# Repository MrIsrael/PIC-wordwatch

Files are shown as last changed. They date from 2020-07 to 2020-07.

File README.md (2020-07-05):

# WordWatch with PIC 16F886 (spanish)
- **This project contains all designs, files and code to build a DIY LED watch, wall mountable, which displays the time with letters, in spanish.**<br />
Resolution: 5 minutes. The words change each 5 minutes.<br />
You can find an example of how it looks when finished, opening image "Wordwatch finished.jpg".<br />
Entire design was built around PIC 16F886 from Microchip.<br />
Schematic and PCB design made using Autodesk EAGLE 8.0.1.<br />
Assembler code edited and compiled using Microchip MPLAB IDE v8.92.<br />
PICkit 2 was used for .hex transfer to microcontroller.<br />

## Instructions
--> Check the components listed in .sch file.<br />
--> Build the PCB using the PDF prints. There is a great guide to do it yourself, [here] (https://www.youtube.com/watch?v=lvNCKwAcg90).<br />
--> Burn the .hex to PIC 16F886, using a PICkit 2 or compatible PIC programmer.<br />
--> Use the "front layout" images to print a scale screen for the leds. I suggest create a wood screen, etching the letters with laser cutter.<br />
--> Use any AC/DC adaptor to power the clock. Minimum output voltage - current required: 6V DC, 300 mA.<br />

## How to set time
--> Once powered on, press the button to enter set mode. Words will start to blink.<br />
--> Press button again to change and set hours.<br />
--> Wait 10 seconds without pressing the button. Now minutes start to blink.<br />
--> Press button to change and set minutes.<br />
--> Wait another 10 seconds without pressing the button. Program will return to normal mode.<br />

## Maintainer
- [Israel Uribe](https://github.com/MrIsrael)

## License
MIT © [WordWatch](https://github.com/MrIsrael/PIC-wordwatch)

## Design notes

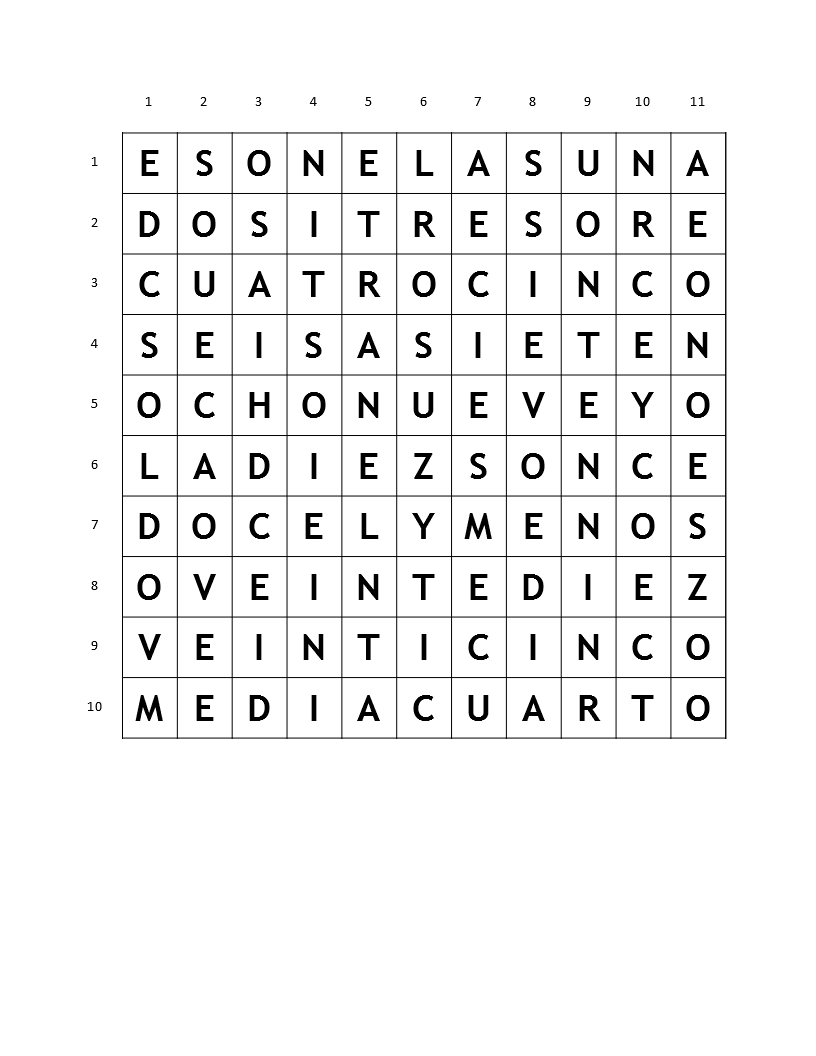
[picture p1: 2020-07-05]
Front layout (black & white).png

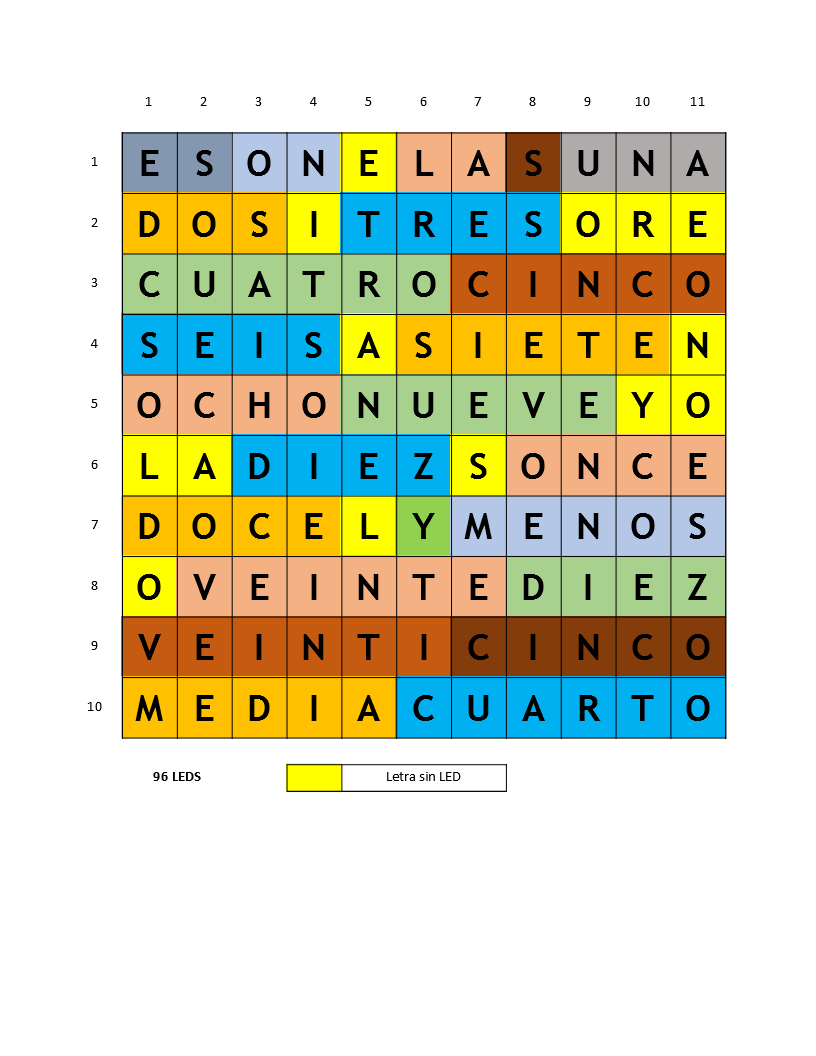
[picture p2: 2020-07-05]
Front layout (color).png

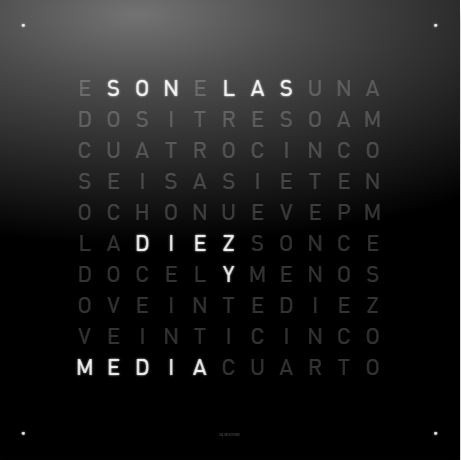
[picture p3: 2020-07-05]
Wordwatch finished.jpg

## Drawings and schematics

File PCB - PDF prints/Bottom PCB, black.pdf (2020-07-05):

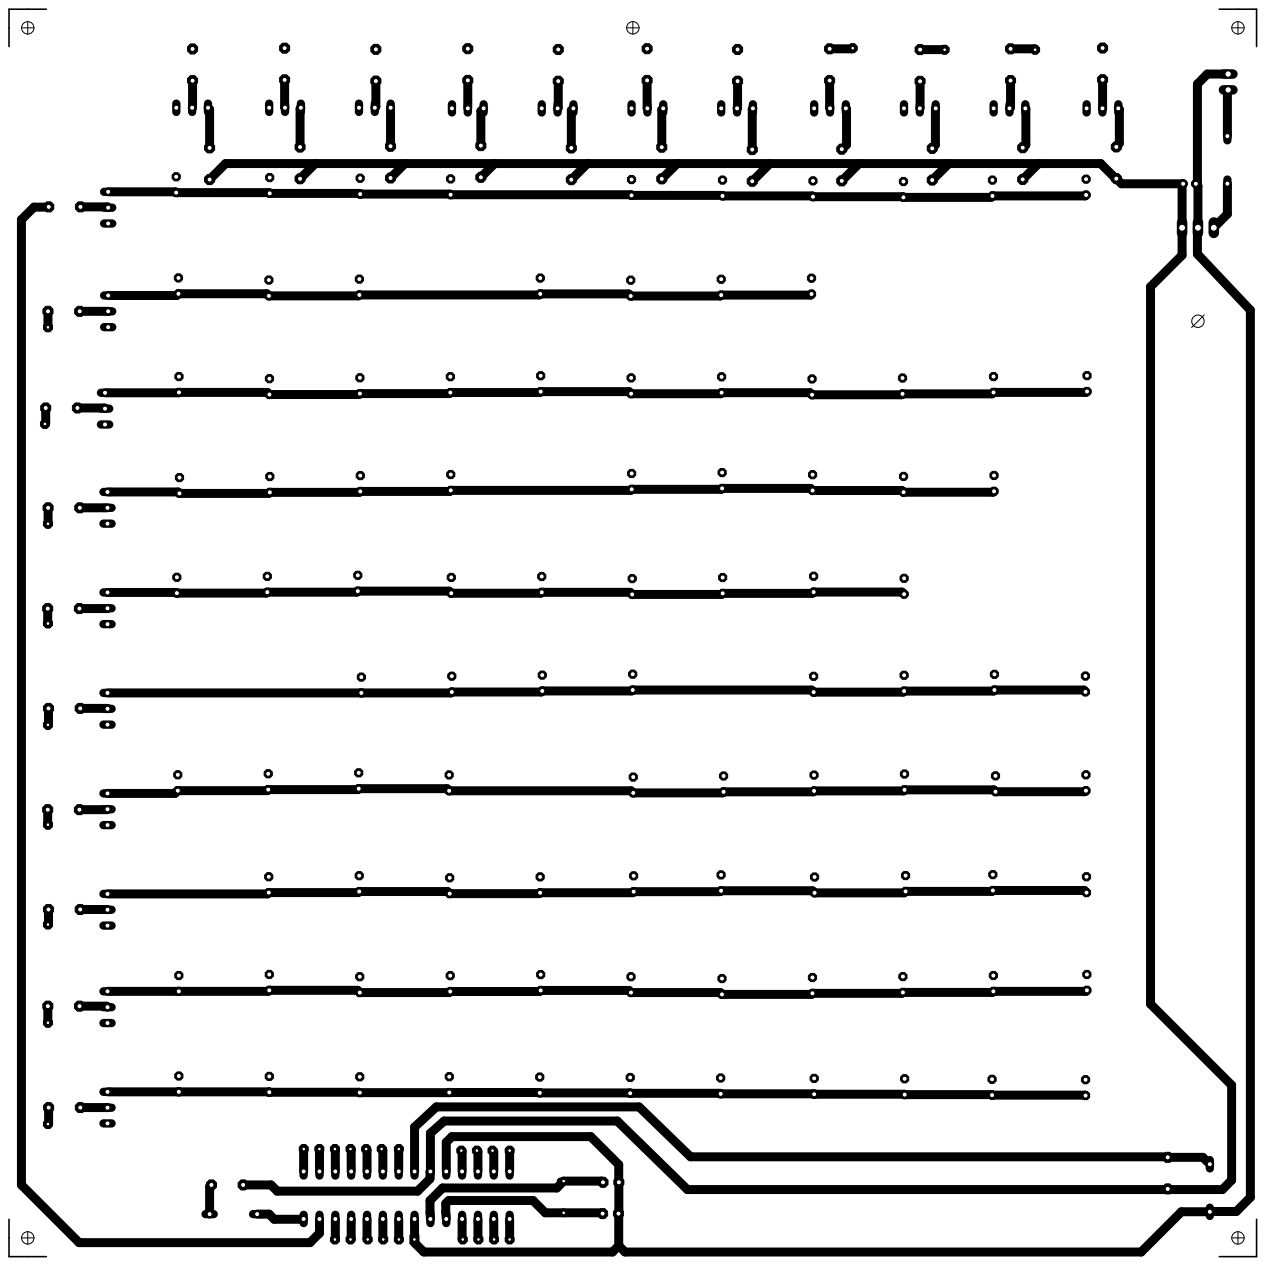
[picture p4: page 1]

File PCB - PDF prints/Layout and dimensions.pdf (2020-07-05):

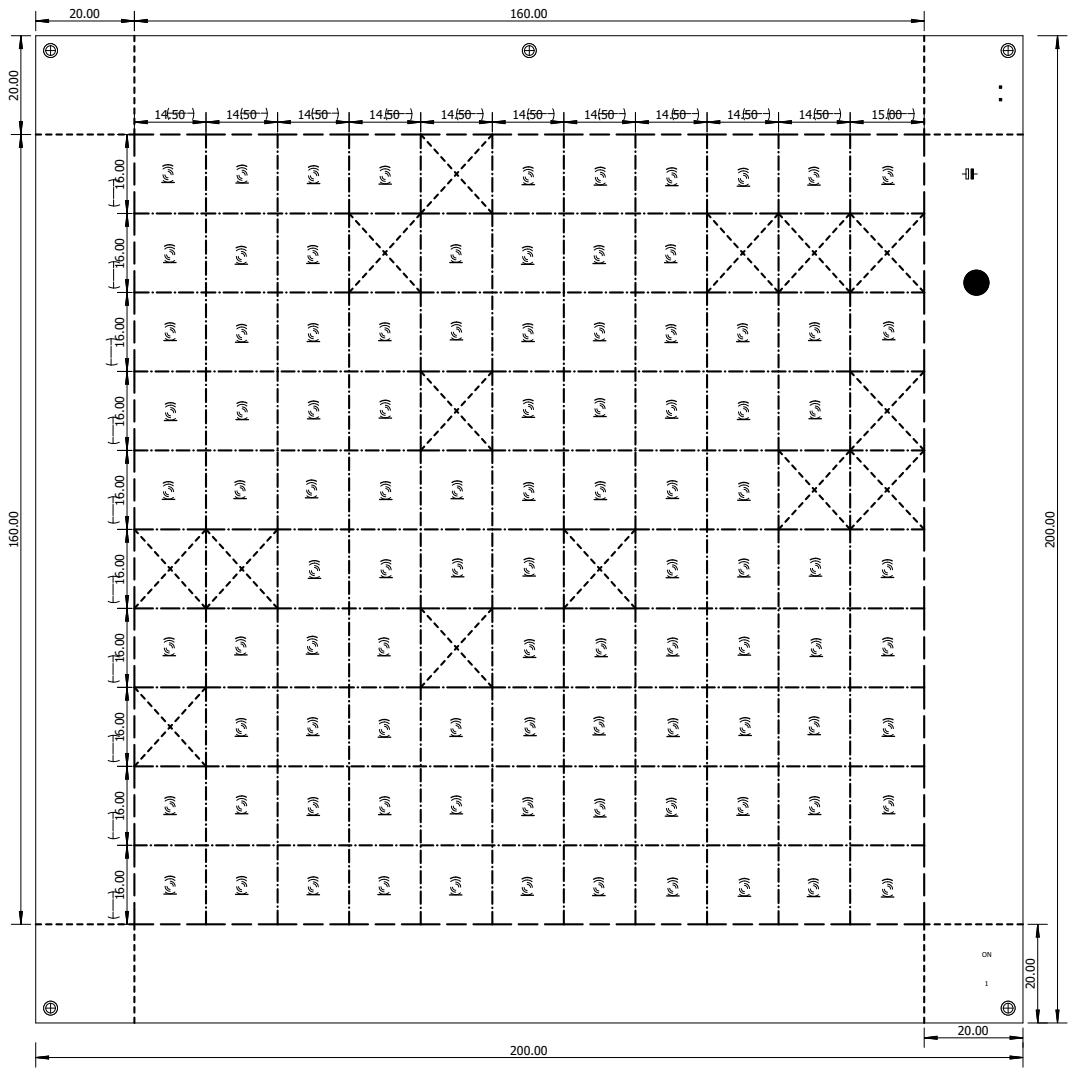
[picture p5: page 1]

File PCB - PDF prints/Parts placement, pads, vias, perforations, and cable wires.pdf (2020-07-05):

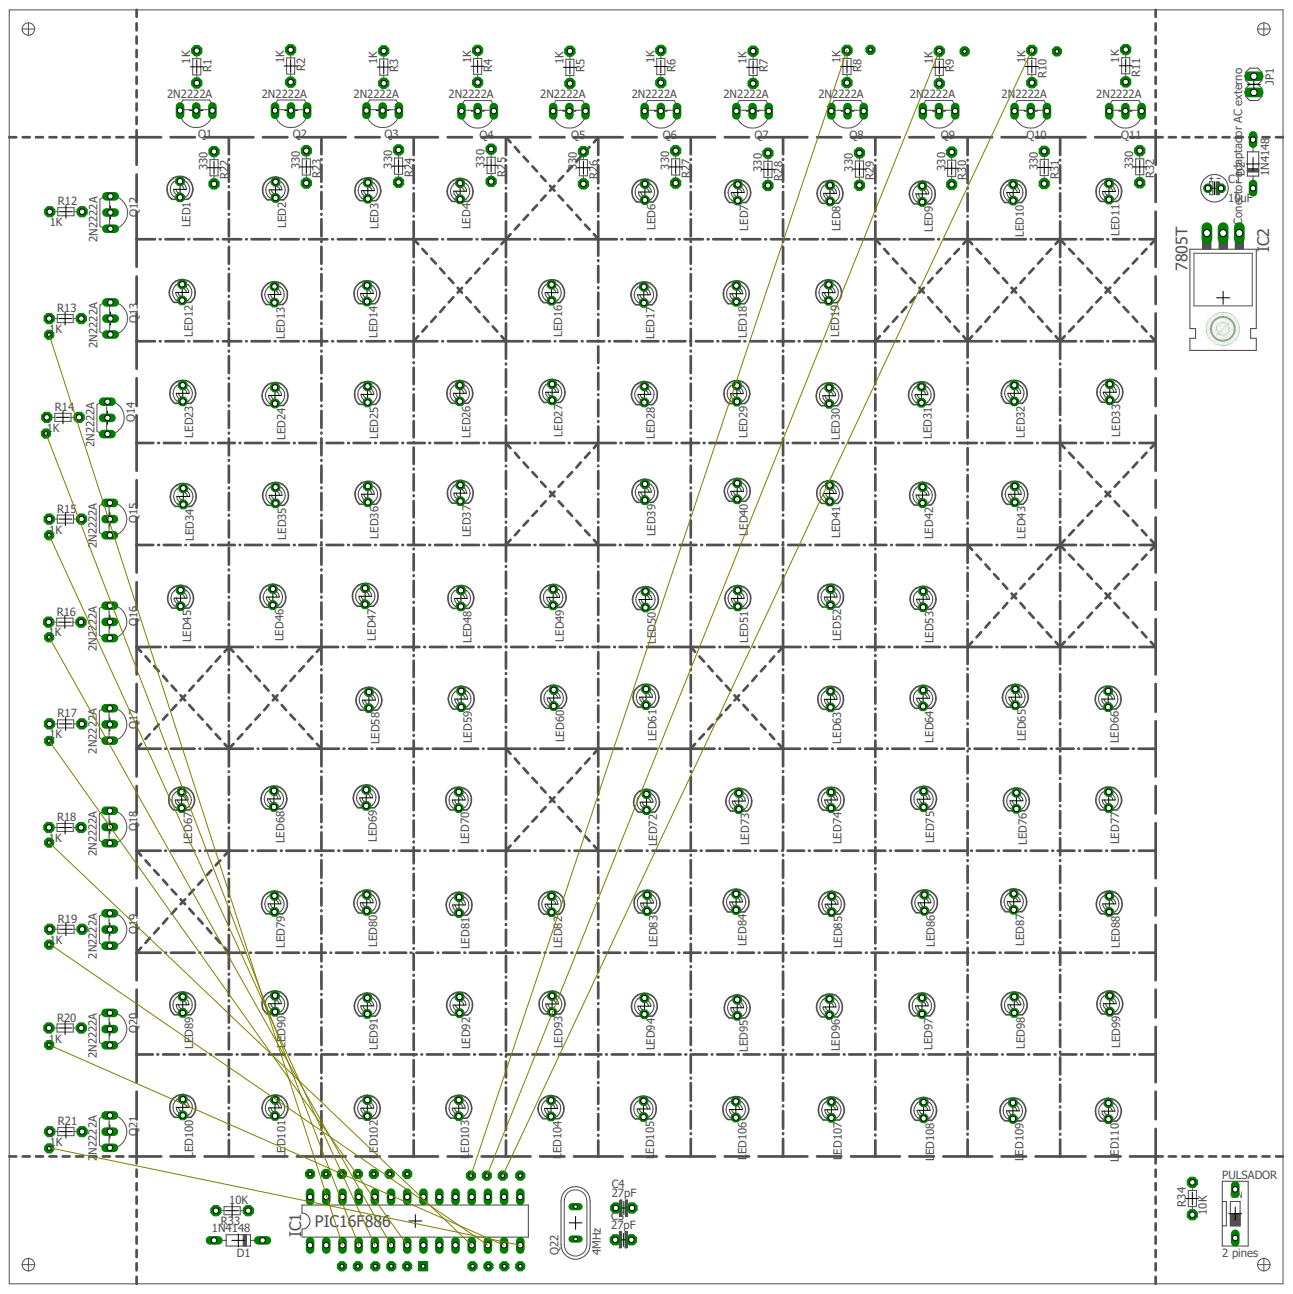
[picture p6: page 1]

Conector adaptador AC externo

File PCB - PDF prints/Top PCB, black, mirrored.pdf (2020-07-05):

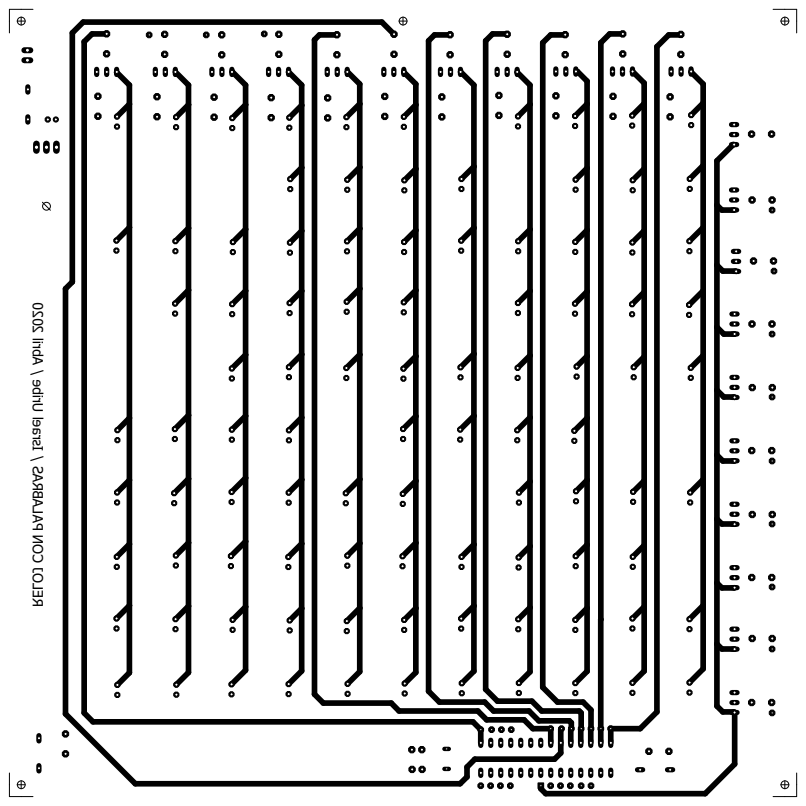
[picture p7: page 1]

RELOJ CON PALABRAS / Israel Uribe / Abril 2020

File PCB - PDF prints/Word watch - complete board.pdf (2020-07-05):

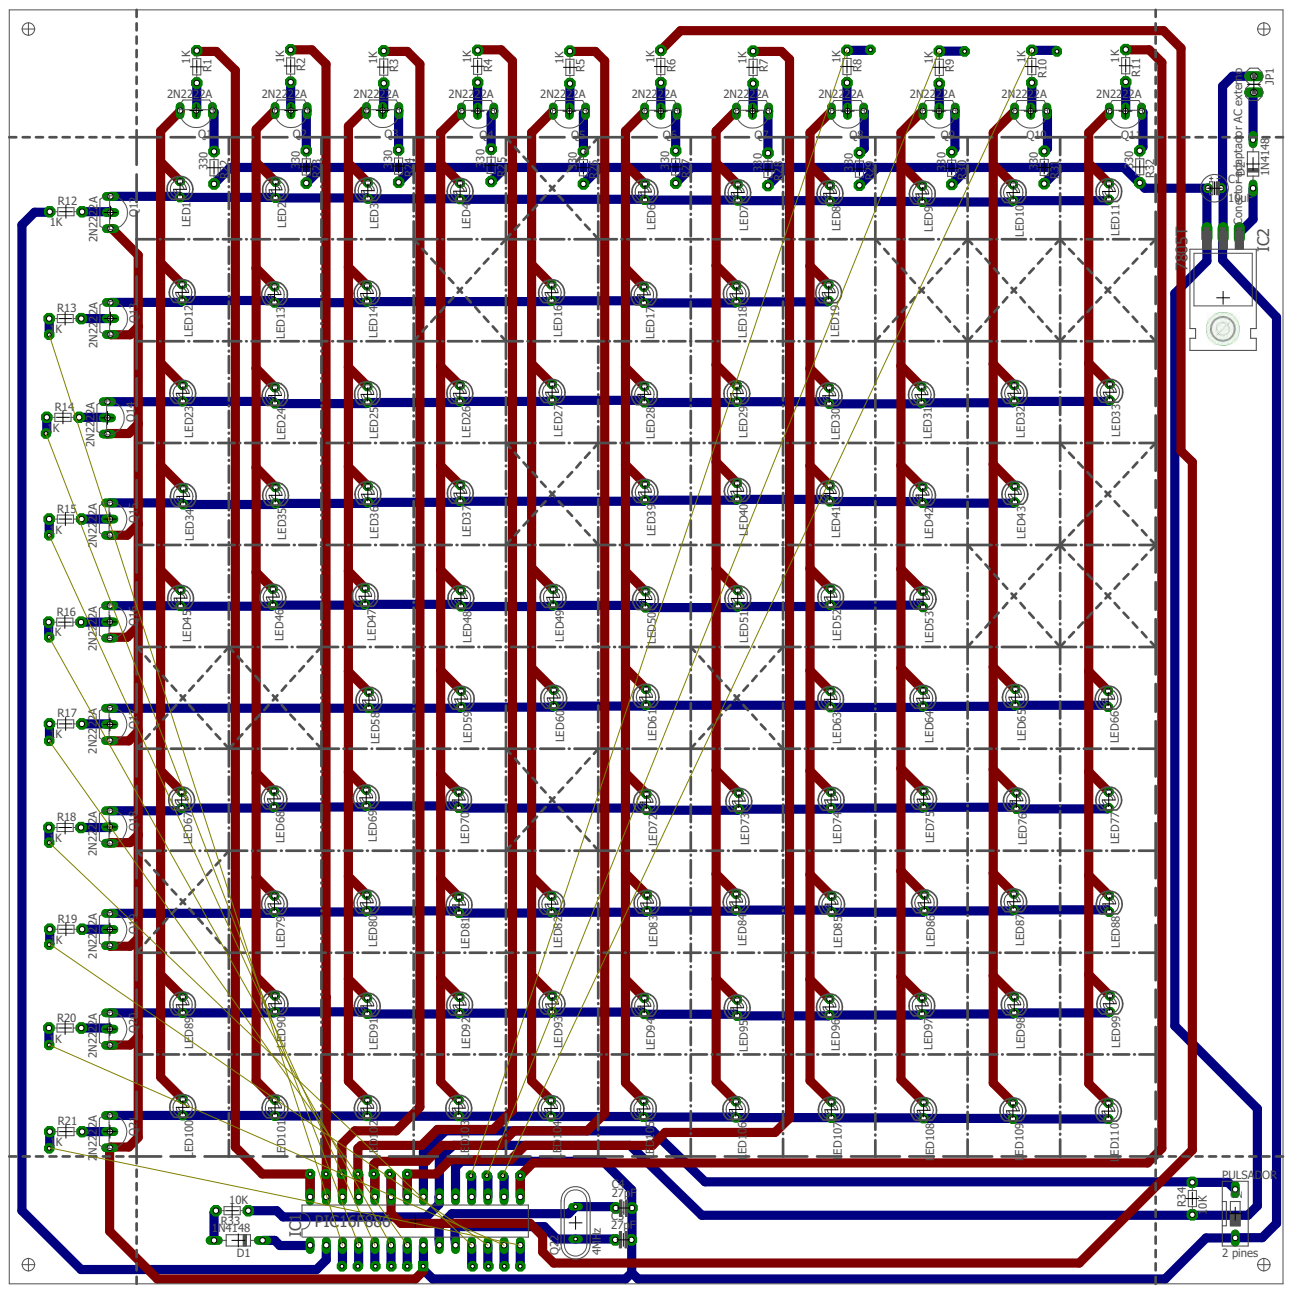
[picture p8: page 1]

Conector adaptador AC externo

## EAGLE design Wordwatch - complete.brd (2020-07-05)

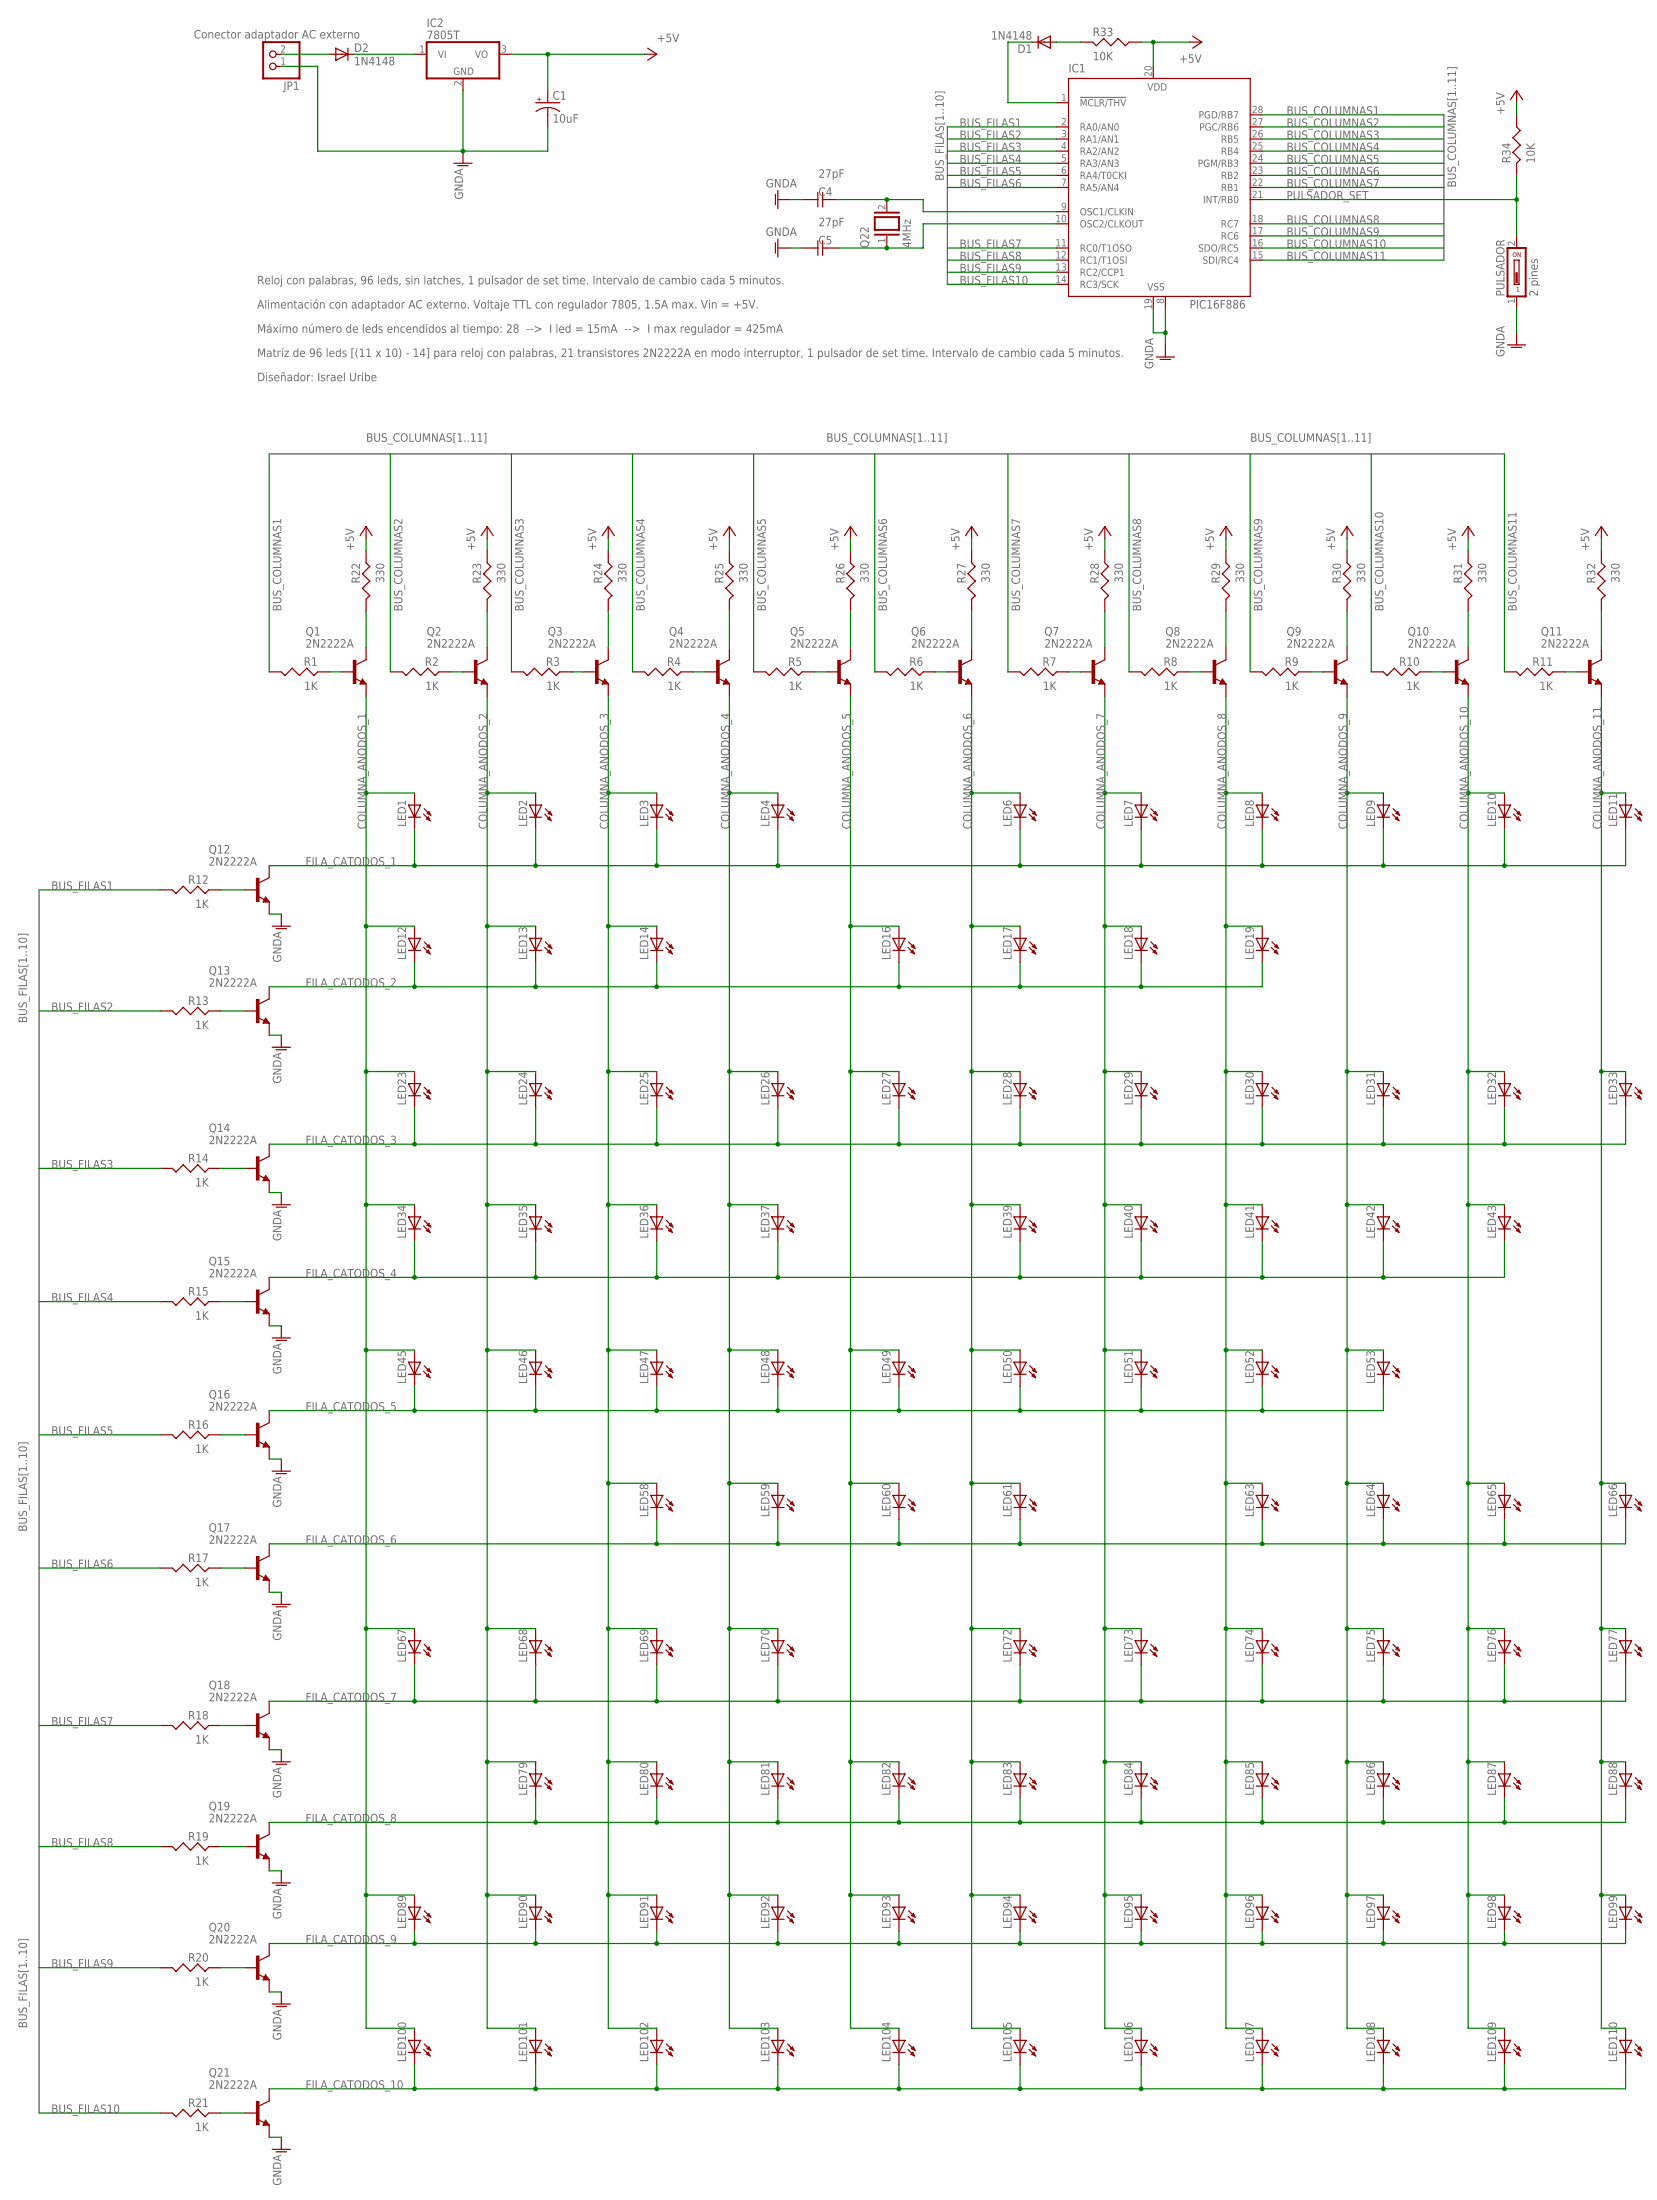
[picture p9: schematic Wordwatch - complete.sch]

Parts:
C1: 10uF; E2-4
C4, C5: 27pF; C-2,5
D1, D2: 1N4148; D-7.5
IC1: PIC16F886; DIL28-3
IC2: 7805T; TO220H
JP1: Conector adaptador AC externo; 1X02
LED1, LED2, LED3, LED4, LED6, LED7, LED8, LED9, LED10, LED11, LED12, LED13, LED14, LED16, LED17, LED18, LED19, LED23, LED24, LED25, LED26, LED27, LED28, LED29, LED30, LED31, LED32, LED33, LED34, LED35, LED36, LED37, LED39, LED40, LED41, LED42, LED43, LED45, LED46, LED47, LED48, LED49, LED50, LED51, LED52, LED53, LED58, LED59, LED60, LED61, LED63, LED64, LED65, LED66, LED67, LED68, LED69, LED70, LED72, LED73, LED74, LED75, LED76, LED77, LED79, LED80, LED81, LED82, LED83, LED84, LED85, LED86, LED87, LED88, LED89, LED90, LED91, LED92, LED93, LED94, LED95, LED96, LED97, LED98, LED99, LED100, LED101, LED102, LED103, LED104, LED105, LED106, LED107, LED108, LED109, LED110: LED3MM
PULSADOR: 2 pines; DS-01
Q1, Q2, Q3, Q4, Q5, Q6, Q7, Q8, Q9, Q10, Q11, Q12, Q13, Q14, Q15, Q16, Q17, Q18, Q19, Q20, Q21: 2N2222A; TO92-CBE
Q22: 4MHz; QS
R1, R2, R3, R4, R5, R6, R7, R8, R9, R10, R11, R12, R13, R14, R15, R16, R17, R18, R19, R20, R21: 1K; R-5
R22, R23, R24, R25, R26, R27, R28, R29, R30, R31, R32: 330; R-5
R33, R34: 10K; R-5

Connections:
+5V: C1.+, IC1.20 (VDD), IC2.3 (VO), R22.2, R23.2, R24.2, R25.2, R26.2, R27.2, R28.2, R29.2, R30.2, R31.2, R32.2, R33.1, R34.1
BUS_COLUMNAS1: IC1.28 (PGD/RB7), R1.1
BUS_COLUMNAS2: IC1.27 (PGC/RB6), R2.1
BUS_COLUMNAS3: IC1.26 (RB5), R3.1
BUS_COLUMNAS4: IC1.25 (RB4), R4.1
BUS_COLUMNAS5: IC1.24 (PGM/RB3), R5.1
BUS_COLUMNAS6: IC1.23 (RB2), R6.1
BUS_COLUMNAS7: IC1.22 (RB1), R7.1
BUS_COLUMNAS8: IC1.18 (RC7), R8.1
BUS_COLUMNAS9: IC1.17 (RC6), R9.1
BUS_COLUMNAS10: IC1.16 (SDO/RC5), R10.1
BUS_COLUMNAS11: IC1.15 (SDI/RC4), R11.1
BUS_FILAS1: IC1.2 (RA0/AN0), R12.1
BUS_FILAS2: IC1.3 (RA1/AN1), R13.1
BUS_FILAS3: IC1.4 (RA2/AN2), R14.1
BUS_FILAS4: IC1.5 (RA3/AN3), R15.1
BUS_FILAS5: IC1.6 (RA4/T0CKI), R16.1
BUS_FILAS6: IC1.7 (RA5/AN4), R17.1
BUS_FILAS7: IC1.11 (RC0/T1OSO), R18.1
BUS_FILAS8: IC1.12 (RC1/T1OSI), R19.1
BUS_FILAS9: IC1.13 (RC2/CCP1), R20.1
BUS_FILAS10: IC1.14 (RC3/SCK), R21.1
COLUMNA_ANODOS_1: LED1.A, LED12.A, LED23.A, LED34.A, LED45.A, LED67.A, LED89.A, LED100.A, Q1.E
COLUMNA_ANODOS_2: LED2.A, LED13.A, LED24.A, LED35.A, LED46.A, LED68.A, LED79.A, LED90.A, LED101.A, Q2.E
COLUMNA_ANODOS_3: LED3.A, LED14.A, LED25.A, LED36.A, LED47.A, LED58.A, LED69.A, LED80.A, LED91.A, LED102.A, Q3.E
COLUMNA_ANODOS_4: LED4.A, LED26.A, LED37.A, LED48.A, LED59.A, LED70.A, LED81.A, LED92.A, LED103.A, Q4.E
COLUMNA_ANODOS_5: LED16.A, LED27.A, LED49.A, LED60.A, LED82.A, LED93.A, LED104.A, Q5.E
COLUMNA_ANODOS_6: LED6.A, LED17.A, LED28.A, LED39.A, LED50.A, LED61.A, LED72.A, LED83.A, LED94.A, LED105.A, Q6.E
COLUMNA_ANODOS_7: LED7.A, LED18.A, LED29.A, LED40.A, LED51.A, LED73.A, LED84.A, LED95.A, LED106.A, Q7.E
COLUMNA_ANODOS_8: LED8.A, LED19.A, LED30.A, LED41.A, LED52.A, LED63.A, LED74.A, LED85.A, LED96.A, LED107.A, Q8.E
COLUMNA_ANODOS_9: LED9.A, LED31.A, LED42.A, LED53.A, LED64.A, LED75.A, LED86.A, LED97.A, LED108.A, Q9.E
COLUMNA_ANODOS_10: LED10.A, LED32.A, LED43.A, LED65.A, LED76.A, LED87.A, LED98.A, LED109.A, Q10.E
COLUMNA_ANODOS_11: LED11.A, LED33.A, LED66.A, LED77.A, LED88.A, LED99.A, LED110.A, Q11.E
FILA_CATODOS_1: LED1.K (C), LED2.K (C), LED3.K (C), LED4.K (C), LED6.K (C), LED7.K (C), LED8.K (C), LED9.K (C), LED10.K (C), LED11.K (C), Q12.C
FILA_CATODOS_2: LED12.K (C), LED13.K (C), LED14.K (C), LED16.K (C), LED17.K (C), LED18.K (C), LED19.K (C), Q13.C
FILA_CATODOS_3: LED23.K (C), LED24.K (C), LED25.K (C), LED26.K (C), LED27.K (C), LED28.K (C), LED29.K (C), LED30.K (C), LED31.K (C), LED32.K (C), LED33.K (C), Q14.C
FILA_CATODOS_4: LED34.K (C), LED35.K (C), LED36.K (C), LED37.K (C), LED39.K (C), LED40.K (C), LED41.K (C), LED42.K (C), LED43.K (C), Q15.C
FILA_CATODOS_5: LED45.K (C), LED46.K (C), LED47.K (C), LED48.K (C), LED49.K (C), LED50.K (C), LED51.K (C), LED52.K (C), LED53.K (C), Q16.C
FILA_CATODOS_6: LED58.K (C), LED59.K (C), LED60.K (C), LED61.K (C), LED63.K (C), LED64.K (C), LED65.K (C), LED66.K (C), Q17.C
FILA_CATODOS_7: LED67.K (C), LED68.K (C), LED69.K (C), LED70.K (C), LED72.K (C), LED73.K (C), LED74.K (C), LED75.K (C), LED76.K (C), LED77.K (C), Q18.C
FILA_CATODOS_8: LED79.K (C), LED80.K (C), LED81.K (C), LED82.K (C), LED83.K (C), LED84.K (C), LED85.K (C), LED86.K (C), LED87.K (C), LED88.K (C), Q19.C
FILA_CATODOS_9: LED89.K (C), LED90.K (C), LED91.K (C), LED92.K (C), LED93.K (C), LED94.K (C), LED95.K (C), LED96.K (C), LED97.K (C), LED98.K (C), LED99.K (C), Q20.C
FILA_CATODOS_10: LED100.K (C), LED101.K (C), LED102.K (C), LED103.K (C), LED104.K (C), LED105.K (C), LED106.K (C), LED107.K (C), LED108.K (C), LED109.K (C), LED110.K (C), Q21.C
GNDA: C1.-, C4.2, C5.2, IC1.8 (VSS), IC1.19 (VSS), IC2.2 (GND), JP1.1, PULSADOR.1, Q12.E, Q13.E, Q14.E, Q15.E, Q16.E, Q17.E, Q18.E, Q19.E, Q20.E, Q21.E
unnamed: Q11.C, R32.1
unnamed: Q10.C, R31.1
unnamed: Q9.C, R30.1
unnamed: Q8.C, R29.1
unnamed: Q7.C, R28.1
unnamed: Q6.C, R27.1
unnamed: Q5.C, R26.1
unnamed: Q4.C, R25.1
unnamed: Q3.C, R24.1
unnamed: Q2.C, R23.1
unnamed: Q1.C, R22.1
unnamed: Q1.B, R1.2
unnamed: Q2.B, R2.2
unnamed: Q3.B, R3.2
unnamed: Q4.B, R4.2
unnamed: Q5.B, R5.2
unnamed: Q6.B, R6.2
unnamed: Q7.B, R7.2
unnamed: Q8.B, R8.2
unnamed: Q9.B, R9.2
unnamed: Q10.B, R10.2
unnamed: Q11.B, R11.2
unnamed: Q12.B, R12.2
unnamed: Q13.B, R13.2
unnamed: Q14.B, R14.2
unnamed: Q15.B, R15.2
unnamed: Q16.B, R16.2
unnamed: Q17.B, R17.2
unnamed: Q18.B, R18.2
unnamed: Q19.B, R19.2
unnamed: Q20.B, R20.2
unnamed: Q21.B, R21.2
unnamed: C4.1, IC1.9 (OSC1/CLKIN), Q22.2
unnamed: D1.A, R33.2
unnamed: C5.1, IC1.10 (OSC2/CLKOUT), Q22.1
unnamed: D1.C, IC1.1 (!MCLR/THV)
unnamed: D2.A, JP1.2
unnamed: D2.C, IC2.1 (VI)
PULSADOR_SET: IC1.21 (INT/RB0), PULSADOR.2, R34.2

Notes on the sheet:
Matríz de 96 leds [(11 x 10) - 14] para reloj con palabras, 21 transistores 2N2222A en modo interruptor, 1 pulsador de set time. Intervalo de cambio cada 5 minutos.
Diseñador: Israel Uribe
Reloj con palabras, 96 leds, sin latches, 1 pulsador de set time. Intervalo de cambio cada 5 minutos.
Alimentación con adaptador AC externo. Voltaje TTL con regulador 7805, 1.5A max. Vin = +5V.
Máximo número de leds encendidos al tiempo: 28 --> I led = 15mA --> I max regulador = 425mA

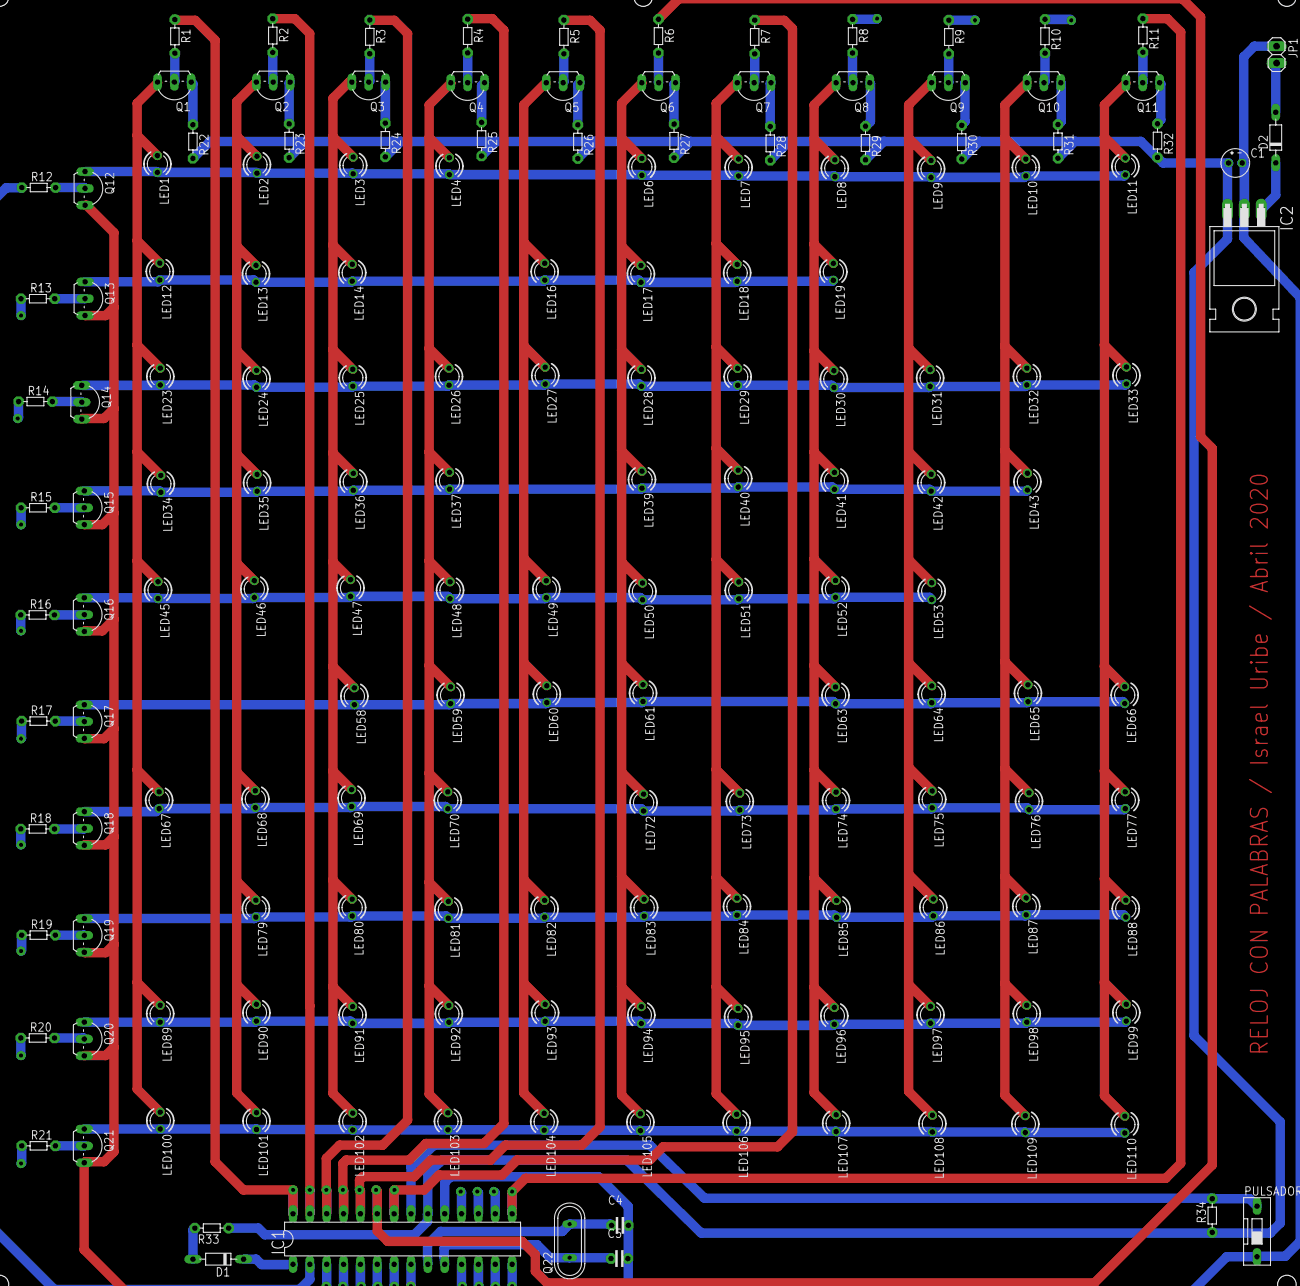
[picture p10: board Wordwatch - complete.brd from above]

Board: 2 copper layers, 161 parts (0 on the bottom side), 83 nets.

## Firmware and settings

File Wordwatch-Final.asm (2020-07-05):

; Reloj con palabras con PIC 16F886, 96 leds, 21 transistores 2N2222A para manjo de corriente, pines I/O del PIC activos altos, 
; control de tiempo con 1 temporizador interno (TMR0), modo set mediante interrupción externa con pulsador conectado a RB0
; Alimentación con adaptador de 8V y regulador 78LS05, Vin = +5V, pulsador de ajuste de intervalos de 5 minutos

; Diseñador: Israel Uribe
; Medellín, Abril 27 de 2020

; PROGRAMA FINAL / Se encienden todas las frases, en el orden correcto, con barrido de leds con TMR0. Cambio de frase con el pulsador RB0-INT; el antirrebote por software funciona bien.
;                  Se muestran las frases a 90 fps, sin parpadeo; cada led se enciende durante 400useg. No hay calentamiento en el regulador.
;				   El modo set funciona perfectamente!

; DEFINICIÓN DEL PROCESADOR Y FRECUENCIA DEL OSCILADOR EXTERNO:
    
	List		p=16F886										; Tipo de procesador
	include		"P16F886.INC"									; Definiciones de registros internos
   	#define		Fosc 4000000									; Velocidad de trabajo

    
; PALABRAS DE CONFIGURACIÓN:									; Ajusta los valores de las palabras de configuración durante el ensamblado. 
																; Los bits no empleados adquieren el valor por defecto.

    __config	_CONFIG1, _LVP_OFF&_PWRTE_ON&_WDT_OFF&_XT_OSC&_FCMEN_OFF	
																; Palabra 1 de configuración
																; Modo debugger deshabilitado (RB6 y RB7 son I/O digitales),
																; programación en bajo voltaje deshabilitada (RB3 es una I/O digital), 
																; Fail-Safe Clock Monitor deshabilitado, code protect desactivado, watchdog timer desactivado, 
																; oscilador externo tipo cristal de cuarzo, power-up timer activado.

    __config	_CONFIG2, _WRT_OFF&_BOR40V						; Palabra 2 de configuración
																; Se desactivó la protección contra escritura de la memoria flash de programa, 
																; Brown-out Reset seleccionado en 4.0V.


; REGISTROS DE USUARIO:											; Rango válido del primer banco de GPR's: h'20' hasta h'7F' inclusive (96 Bytes). Son 368 en total.
    
;MSE_Delay_V				equ	h'20'							; Dirección de inicio de los 3 registros empleados por la macro de temporización "MSE_Delay.inc".

salvar_status_int			equ	h'23'						 	; h'23': Dirección de inicio de otros GPR's del programa. 
salvar_W_int				equ	h'24'						
		
cont_segundos				equ	h'25'							; Con estos 2 contadores se registran 60 x 5 = 300 segundos = 5 minutos = 750000 desbordes de TMR0.
cont_minutos				equ	h'26'
display_horas				equ	h'27'							; Contador de intervalo de cambio de display cada hora. Tiene 12 valores posibles.
display_minutos				equ	h'28'							; Contador de intervalo de cambio de display cada 5 minutos. Tiene 11 valores posibles, pues en el cambio de hora (cero minutos) no se encienden leds.
contador_set				equ	h'29'

cont_1seg_TMR1				equ h'2A'							; TMR1 temporiza 500mseg; para temporizar 1 segundo, TMR1 debe desbordarse 2 veces. Con este registro se controla esa cuenta.

flags						equ h'2B'							; Registro de flags GPR.

; CONSTANTES:

; Bits del GPR "flags":
TMR0_FULL					equ 7								; Bit 7 = si está en 1, el TMR0 no se ha desbordado; si está en 0, TMR0 ya se desbordó (función inversa de INTCON,T0IF).
ONE_SEG						equ 6								; Bit 6 = si está en 1, TMR0 ya temporizó 1 segundo; si está en 0, todavía está temporizando.
CAMBIO_FRASE				equ 5								; Bit 5 = si está en 1, le indica al programa principal que se presionó el pulsador, y se debe entrar a modo set / mostrar una nueva frase.
SET_HORAS					equ 4								; Bit 4 = si está en 1, se está en modo set / configuración de horas.
SET_MINUTOS					equ 3								; Bit 3 = si está en 1, se está en modo set / configuración de minutos.


; VECTORES DE INICIO Y DE INTERRUPCIÓN:
		
			org		0x00
			goto	Inicio										; Vector de reset.
			org		0x04
			goto	inter										; Vector de interrupción. Indica salto a rutina de interrupción "inter".

			org		0x05										; Vector de inicio de grabación en memoria Flash del PIC.
			

; INCLUSIÓN DE SUBRUTINAS *.inc:

;			include	"MSE_Delay.inc"								; Incluir rutinas de temporización 
																; (PONER SIEMPRE ACÁ ESTE "include", que realmente es una subrutina).
			
; RUTINA DE INTERRUPCIÓN:

inter		bcf		INTCON,GIE									; Deshabilitar todas las interrupciones, hasta la instrucción retfie, que las habilitará de nuevo.
			movwf	salvar_W_int								; Se salva el contenido del registro "W" anterior a la interrupción.
			movf	STATUS,W
			movwf	salvar_status_int							; Se salva el contenido del registro "STATUS" anterior a la interrupción.

; CONTENIDO DE LA INTERRUPCIÓN:

			btfss	INTCON,INTE									; Interrupción por pulsación externa en RB0 habilitada? No se está haciendo temporización antirrebote?
			goto	inter2										; No, INTE deshabilitada. Se está haciendo la temporización antirrebote, de hecho. Verificar otros flags de interrupción.
			btfsc	INTCON,INTF									; Si, INTE habilitada. RB0 está pulsado y se encendió el flag INTF? (así INTE esté deshabilitado?)
			goto	inter_INTE									; Si. Las dos condiciones anteriores se cumplieron. Ir a la rutina de interrupción por pulsación externa en RB0.
inter2		btfsc	PIR1,TMR1IF									; Se entró a la rutina de interrupción por desborde del Timer1?
			goto	inter_T1IE									; Si. Ir a la rutina de interrupción por desborde de TMR1.
			btfsc	INTCON,T0IF									; Se entró a la rutina de interrupción por desborde del TMR0? --> Se entra aquí cada 400useg, siempre.
			goto	inter_T0IE									; Si. Ir a la rutina de interrupción por desborde de TMR0.
			goto	inter_out

inter_T1IE	incf	cont_1seg_TMR1,F

			movlw	d'1'										; El Timer 1 se desbordó ya 1 vez (500mseg)? Pasó ya medio segundo?
			xorwf	cont_1seg_TMR1,W
			btfsc	STATUS,Z									; No. Seguir.
			bsf		INTCON,INTE									; Si. Habilitar la interrupción por pulsación externa en RB0, pues en este punto la temporización antirrebote ya obligatoriamente terminó.

			movlw	d'2'										; El Timer 1 se desbordó ya 2 veces seguidas (500mseg c/u)? Pasó ya 1 segundo?
			xorwf	cont_1seg_TMR1,W
			btfss	STATUS,Z
			goto	inter_set_TMR1								; No. Configurar nuevamente TMR1 para que temporice 500mseg.
			clrf	cont_1seg_TMR1								; Si. Reiniciar el contador.
			bsf		flags,ONE_SEG								; También activar el flag correspondiente (temporización de 1 segundo completada).

inter_set_TMR1
			movlw	b'00001011'
			movwf	TMR1H										; Valor de carga inicial del Timer 1 (de 16 bits), para temporizar 500000us = 0.5seg
			movlw	b'11011100'
			movwf	TMR1L
			bcf		PIR1,TMR1IF									; Borrar flag de interrupción por desbordamiento del Timer 1.
			movlw	b'00110001'									; Configuración del Timer 1: Siempre contando, prescaler 1:8, oscilador LP apagado, pulsos por oscilador interno (Fosc/4), Habilitado (comienza el conteo)
			movwf	T1CON
			goto	inter_out
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
